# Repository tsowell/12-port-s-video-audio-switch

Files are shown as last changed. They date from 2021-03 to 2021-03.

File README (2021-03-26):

KiCad design, AVR code, and misc CAD files for a 12-port S-Video/audio
switch with VFD display, described in detail here:

https://blog.ldtlb.com/2021/03/25/12-port-s-video-audio-switch.html

The design in the KiCad files has multiple flaws.  Most importantly, the
terminating resistors for the luminance and chroma inputs were omitted, and the
+5VD voltage regualt can become quite hot without a large heatsink.  These are
explained in more detail in the post above.

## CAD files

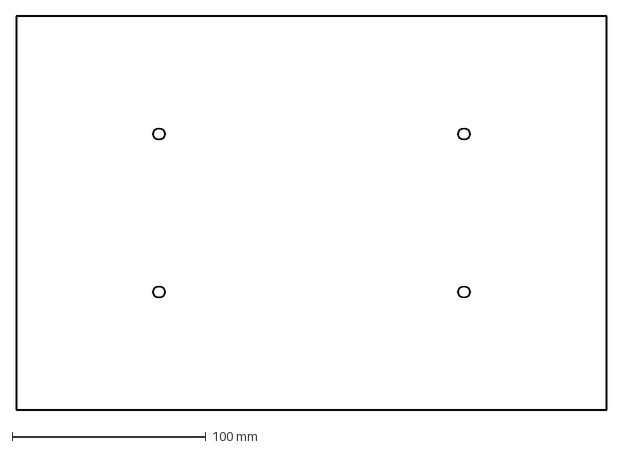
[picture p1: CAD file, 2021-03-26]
dxf/bottom.dxf
304.8 x 203.2 mm

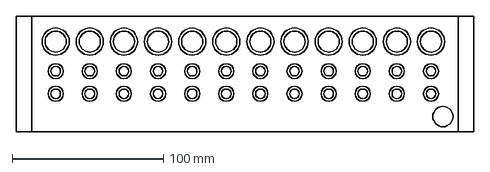
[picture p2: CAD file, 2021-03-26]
dxf/back.dxf
302.2 x 76.2 mm

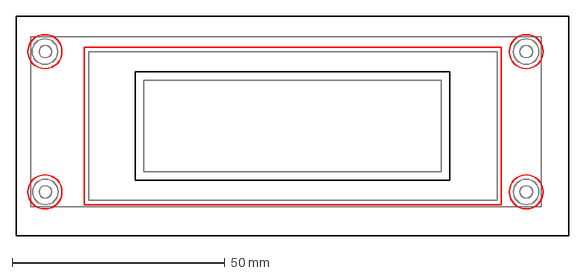
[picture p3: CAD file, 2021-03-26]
dxf/bezel.dxf
129.8 x 51.6 mm

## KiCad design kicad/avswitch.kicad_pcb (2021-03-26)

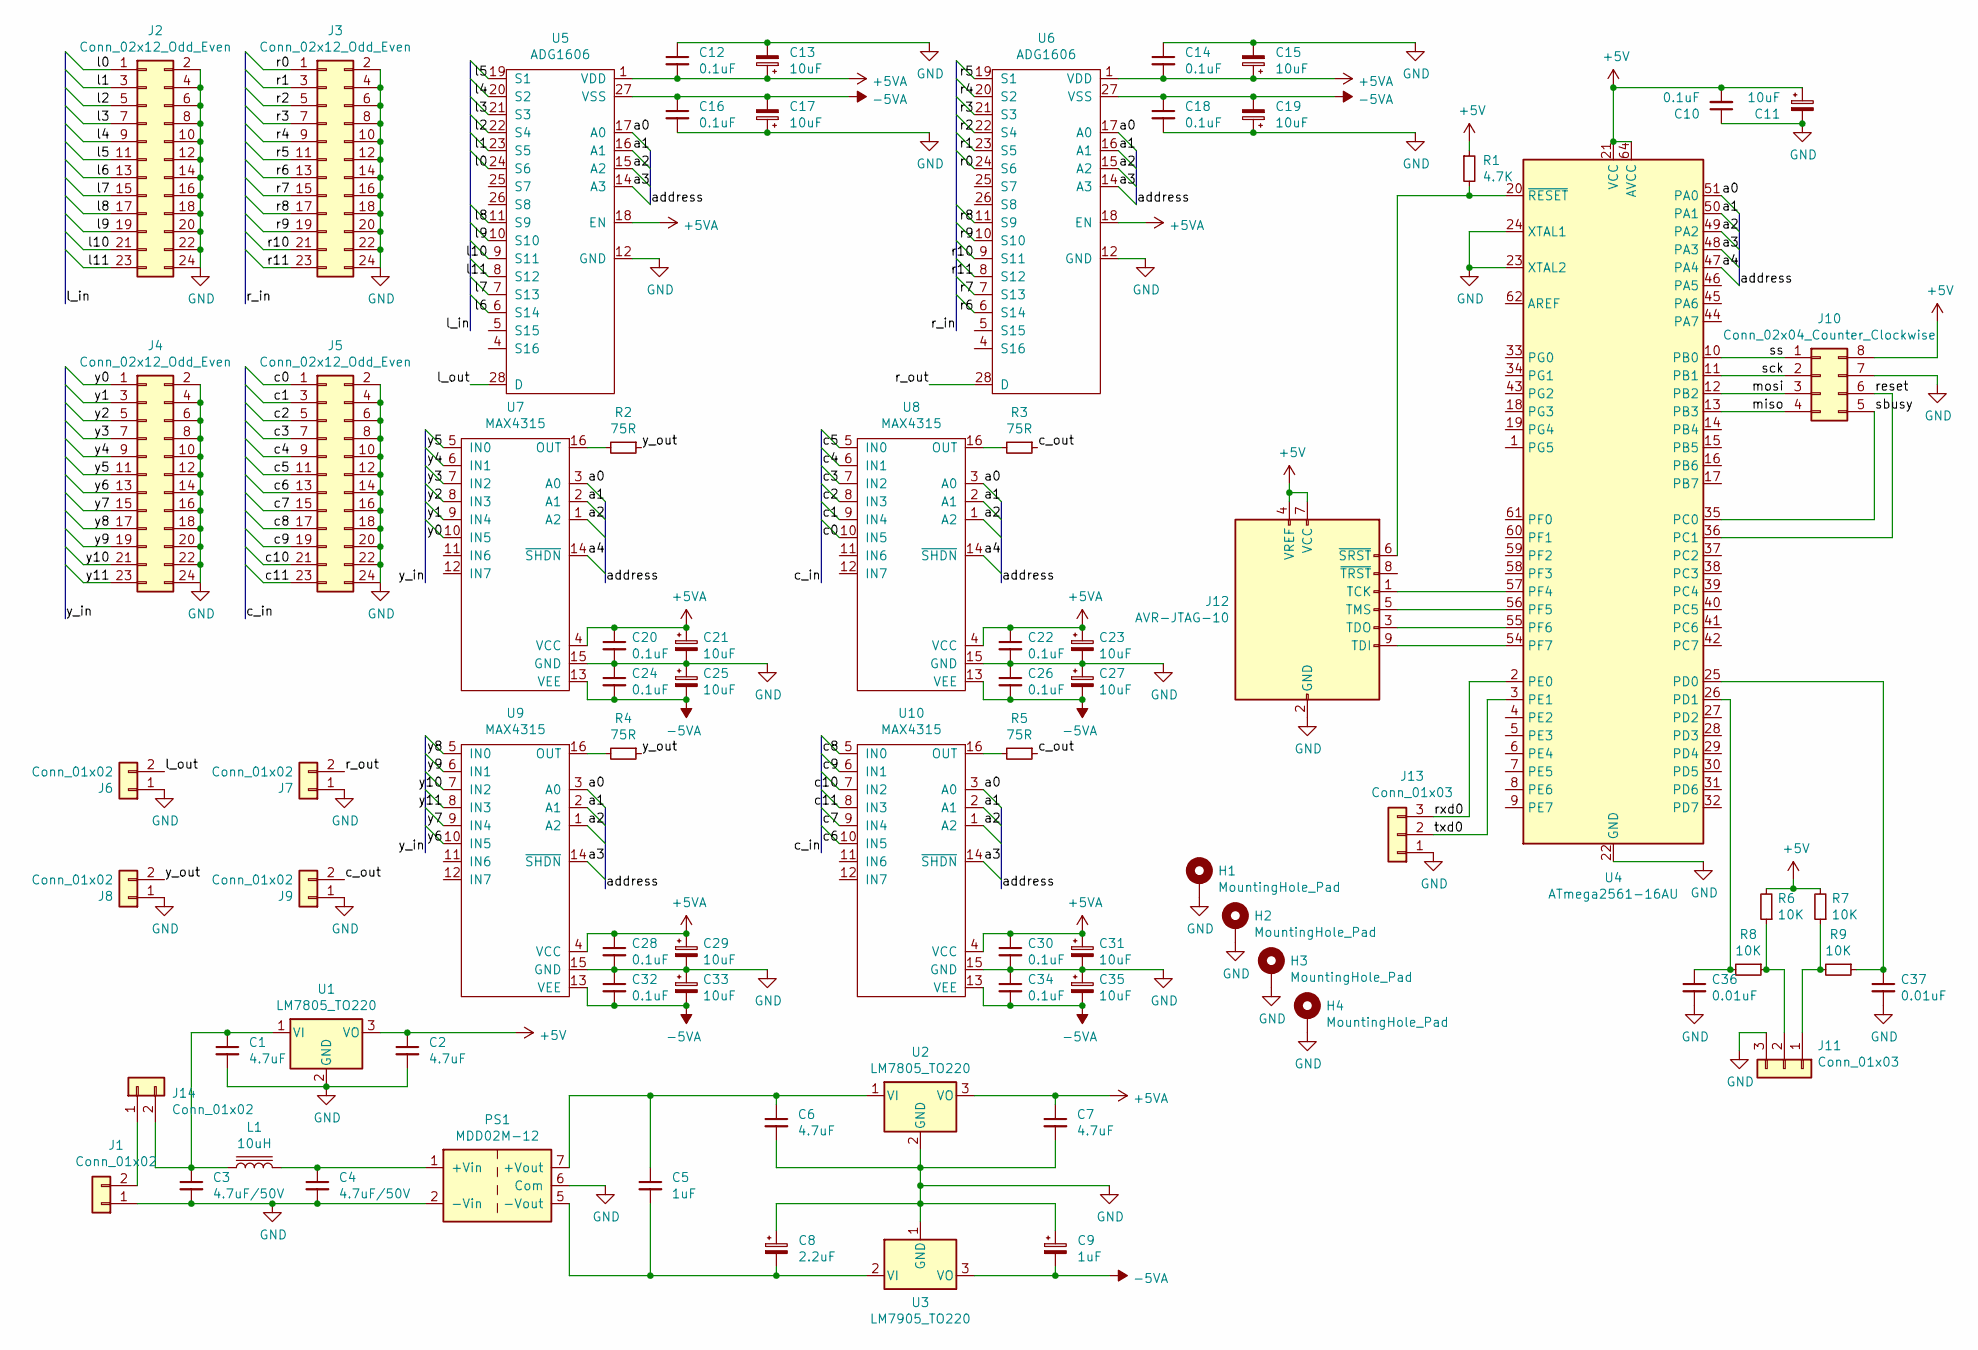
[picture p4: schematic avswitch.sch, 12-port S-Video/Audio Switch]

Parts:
C1, C2, C6, C7: 4.7uF; C_1206_3216Metric_Pad1.42x1.75mm_HandSolder; Part 399-3524-1-ND
C3, C4: 4.7uF/50V; C_1206_3216Metric_Pad1.42x1.75mm_HandSolder; Part 399-11685-1-ND
C5: 1uF; C_1206_3216Metric_Pad1.42x1.75mm_HandSolder; Part 399-1254-1-ND
C8: 2.2uF; CP_EIA-3216-18_Kemet-A_Pad1.58x1.35mm_HandSolder; Part 399-3691-1-ND
C9: 1uF; CP_EIA-3216-18_Kemet-A_Pad1.58x1.35mm_HandSolder; Part 399-3678-1-ND
C10, C12, C14, C16, C18, C20, C22, C24, C26, C28, C30, C32, C34: 0.1uF; C_1206_3216Metric_Pad1.42x1.75mm_HandSolder; Part 399-9305-1-ND
C11, C13, C15, C17, C19, C21, C23, C25, C27, C29, C31, C33, C35: 10uF; CP_Elec_4x5.4; Part 493-2173-1-ND
C36, C37: 0.01uF; C_1206_3216Metric_Pad1.42x1.75mm_HandSolder; Part 399-14645-1-ND
H1, H2, H3, H4: MountingHole_Pad; MountingHole_3.2mm_M3_Pad_Via
J1, J6, J7, J8, J9, J14: Conn_01x02; Molex_KK-254_AE-6410-02A_1x02_P2.54mm_Vertical; Part WM2700-ND
J2, J3, J4, J5: Conn_02x12_Odd_Even; PinHeader_2x12_P2.54mm_Vertical; Part ED10525-ND
J10: Conn_02x04_Counter_Clockwise; PinHeader_2x04_P2.54mm_Vertical; Part 732-5395-ND
J11: Conn_01x03; Molex_KK-254_AE-6410-03A_1x03_P2.54mm_Vertical; Part WM2701-ND
J12: AVR-JTAG-10; PinHeader_2x05_P1.27mm_Vertical; Part 1175-1627-ND
J13: Conn_01x03; PinHeader_1x03_P2.54mm_Vertical
L1: 10uH; L_1206_3216Metric_Pad1.42x1.75mm_HandSolder; Part 541-2607-6-ND
PS1: MDD02M-12; Part 1866-3383-ND
R1: 4.7K; R_1206_3216Metric_Pad1.42x1.75mm_HandSolder; Part 311-4.7KERCT-ND
R2, R3, R4, R5: 75R; R_1206_3216Metric_Pad1.42x1.75mm_HandSolder; Part 311-75ERCT-ND
R6, R7, R8, R9: 10K; R_1206_3216Metric_Pad1.42x1.75mm_HandSolder; Part 311-10KERCT-ND
U1, U2: LM7805_TO220; TO-220-3_Vertical; Part 296-47192-ND
U3: LM7905_TO220; TO-220-3_Vertical; Part LM7905CTNS/NOPB-ND
U4: ATmega2561-16AU; TQFP-64_14x14mm_P0.8mm; Part ATMEGA2561-16AURCT-ND
U5, U6: ADG1606; TSSOP-28_4.4x9.7mm_P0.65mm; Part ADG1606BRUZ-REEL7CT-ND
U7, U8, U9, U10: MAX4315; SOIC-16_3.9x9.9mm_P1.27mm

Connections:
+5V: C2.1, C10.2, C11.1, J10.8, J12.4 (VREF), J12.7 (VCC), R1.1, R6.2, R7.2, U1.3 (VO), U4.21 (VCC), U4.52 (VCC), U4.64 (AVCC)
+5VA: C7.1, C12.2, C13.1, C14.2, C15.1, C20.1, C21.1, C22.1, C23.1, C28.1, C29.1, C30.1, C31.1, U2.3 (VO), U5.1 (VDD), U5.18 (EN), U6.1 (VDD), U6.18 (EN), U7.4 (VCC), U8.4 (VCC), U9.4 (VCC), U10.4 (VCC)
-5VA: C9.2, C16.1, C17.2, C18.1, C19.2, C24.2, C25.2, C26.2, C27.2, C32.2, C33.2, C34.2, C35.2, U3.3 (VO), U5.27 (VSS), U6.27 (VSS), U7.13 (VEE), U8.13 (VEE), U9.13 (VEE), U10.13 (VEE)
/a0: U4.51 (PA0), U5.17 (A0), U6.17 (A0), U7.3 (A0), U8.3 (A0), U9.3 (A0), U10.3 (A0)
/a1: U4.50 (PA1), U5.16 (A1), U6.16 (A1), U7.2 (A1), U8.2 (A1), U9.2 (A1), U10.2 (A1)
/a2: U4.49 (PA2), U5.15 (A2), U6.15 (A2), U7.1 (A2), U8.1 (A2), U9.1 (A2), U10.1 (A2)
/a3: U4.48 (PA3), U5.14 (A3), U6.14 (A3), U9.14 (~SHDN), U10.14 (~SHDN)
/a4: U4.47 (PA4), U7.14 (~SHDN), U8.14 (~SHDN)
/c0: J5.1, U8.10 (IN5)
/c1: J5.3, U8.9 (IN4)
/c2: J5.5, U8.8 (IN3)
/c3: J5.7, U8.7 (IN2)
/c4: J5.9, U8.6 (IN1)
/c5: J5.11, U8.5 (IN0)
/c6: J5.13, U10.10 (IN5)
/c7: J5.15, U10.9 (IN4)
/c8: J5.17, U10.5 (IN0)
/c9: J5.19, U10.6 (IN1)
/c10: J5.21, U10.7 (IN2)
/c11: J5.23, U10.8 (IN3)
/c_out: J9.2, R3.1, R5.1
/l0: J2.1, U5.24 (S6)
/l1: J2.3, U5.23 (S5)
/l2: J2.5, U5.22 (S4)
/l3: J2.7, U5.21 (S3)
/l4: J2.9, U5.20 (S2)
/l5: J2.11, U5.19 (S1)
/l6: J2.13, U5.6 (S14)
/l7: J2.15, U5.7 (S13)
/l8: J2.17, U5.11 (S9)
/l9: J2.19, U5.10 (S10)
/l10: J2.21, U5.9 (S11)
/l11: J2.23, U5.8 (S12)
/l_out: J6.2, U5.28 (D)
/miso: J10.4, U4.13 (PB3)
/mosi: J10.3, U4.12 (PB2)
/r0: J3.1, U6.24 (S6)
/r1: J3.3, U6.23 (S5)
/r2: J3.5, U6.22 (S4)
/r3: J3.7, U6.21 (S3)
/r4: J3.9, U6.20 (S2)
/r5: J3.11, U6.19 (S1)
/r6: J3.13, U6.6 (S14)
/r7: J3.15, U6.7 (S13)
/r8: J3.17, U6.11 (S9)
/r9: J3.19, U6.10 (S10)
/r10: J3.21, U6.9 (S11)
/r11: J3.23, U6.8 (S12)
/r_out: J7.2, U6.28 (D)
/reset: J10.6, U4.36 (PC1)
/rxd0: J13.3, U4.2 (PE0)
/sbusy: J10.5, U4.35 (PC0)
/sck: J10.2, U4.11 (PB1)
/ss: J10.1, U4.10 (PB0)
/txd0: J13.2, U4.3 (PE1)
/y0: J4.1, U7.10 (IN5)
/y1: J4.3, U7.9 (IN4)
/y2: J4.5, U7.8 (IN3)
/y3: J4.7, U7.7 (IN2)
/y4: J4.9, U7.6 (IN1)
/y5: J4.11, U7.5 (IN0)
/y6: J4.13, U9.10 (IN5)
/y7: J4.15, U9.9 (IN4)
/y8: J4.17, U9.5 (IN0)
/y9: J4.19, U9.6 (IN1)
/y10: J4.21, U9.7 (IN2)
/y11: J4.23, U9.8 (IN3)
/y_out: J8.2, R2.1, R4.1
GND: C1.2, C2.2, C3.2, C4.2, C6.2, C7.2, C8.1, C9.1, C10.1, C11.2, C12.1, C13.2, C14.1, C15.2, C16.2, C17.1, C18.2, C19.1, C20.2, C21.2, C22.2, C23.2, C24.1, C25.1, C26.1, C27.1, C28.2, C29.2, C30.2, C31.2, C32.1, C33.1, C34.1, C35.1, C36.2, C37.2, H1.1, H2.1, H3.1, H4.1, J1.1, J2.2, J2.4, J2.6, J2.8, J2.10, J2.12, J2.14, J2.16, J2.18, J2.20, J2.22, J2.24, J3.2, J3.4, J3.6, J3.8, J3.10, J3.12, J3.14, J3.16, J3.18, J3.20, J3.22, J3.24, J4.2, J4.4, J4.6, J4.8, J4.10, J4.12, J4.14, J4.16, J4.18, J4.20, J4.22, J4.24, J5.2, J5.4, J5.6, J5.8, J5.10, J5.12, J5.14, J5.16, J5.18, J5.20, J5.22, J5.24, J6.1, J7.1, J8.1, J9.1, J10.7, J11.3, J12.2 (GND), J12.10 (GND), J13.1, PS1.2 (-Vin), PS1.6 (Com), U1.2 (GND), U2.2 (GND), U3.1 (GND), U4.22 (GND), U4.23 (XTAL2), U4.24 (XTAL1), U4.53 (GND), U4.63 (GND), U5.12 (GND), U6.12 (GND), U7.15 (GND), U8.15 (GND), U9.15 (GND), U10.15 (GND)
unnamed: C1.1, C3.1, J14.2, L1.1, U1.1 (VI)
unnamed: C4.1, L1.2, PS1.1 (+Vin)
unnamed: C5.1, C6.1, PS1.7 (+Vout), U2.1 (VI)
unnamed: C5.2, C8.2, PS1.5 (-Vout), U3.2 (VI)
unnamed: C36.1, R8.2, U4.26 (PD1)
unnamed: C37.1, R9.1, U4.25 (PD0)
unnamed: J1.2, J14.1
unnamed: J11.1, R7.1, R9.2
unnamed: J11.2, R6.1, R8.1
unnamed: J12.1 (TCK), U4.57 (PF4)
unnamed: J12.3 (TDO), U4.55 (PF6)
unnamed: J12.5 (TMS), U4.56 (PF5)
unnamed: J12.6 (~SRST), R1.2, U4.20 (~RESET)
unnamed: J12.9 (TDI), U4.54 (PF7)
unnamed: R2.2, U7.16 (OUT)
unnamed: R3.2, U8.16 (OUT)
unnamed: R4.2, U9.16 (OUT)
unnamed: R5.2, U10.16 (OUT)

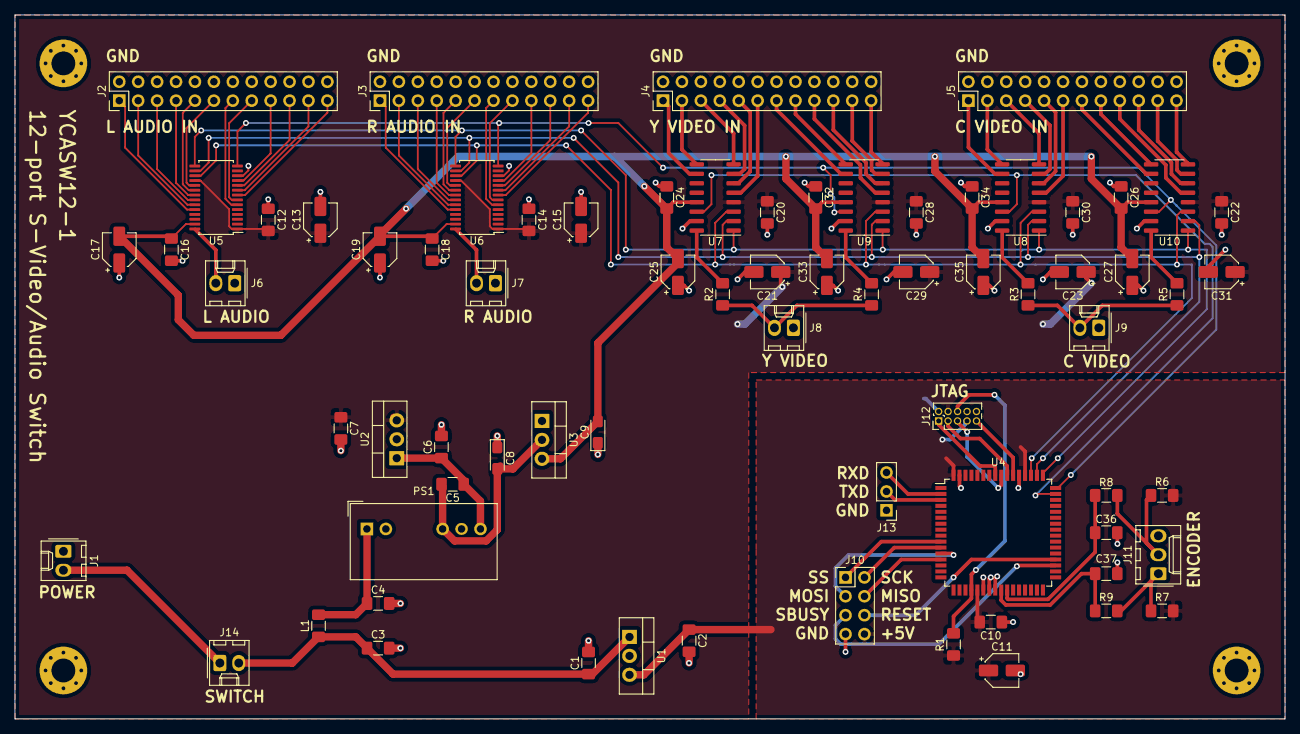
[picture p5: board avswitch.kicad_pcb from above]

Board: 2 copper layers, 170.5 x 94.5 mm, 76 parts (0 on the bottom side), 87 nets.

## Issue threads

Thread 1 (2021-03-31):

Add license information

vazhnov, 2021-03-31:
Hello!

I found link to this project from https://hackaday.com/2021/03/30/custom-built-12-port-a-v-switch-keeps-crt-well-fed/

Could you please add information about license of this repository — is it allowed to copy, change and use the code and board schematic files in any purpose?
It would be great to see any popular open source license.

tsowell, 2021-03-31:
Hi, yes, sorry I forgot that!  I'm releasing the contents of this repository under an MIT license, and I've added the licensing file: (64fa706a436f14960ff93261482801e07a017a8b).  I'm new to hardware licensing, but from what I understand, that should be sufficient.  Please let me know if I did anything wrong though.  Thanks for your interest!

vazhnov, 2021-03-31:
@tsowell , Thank you!

Closed 2021-03-31.

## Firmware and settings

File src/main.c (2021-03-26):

#define F_CPU 8000000UL

#include <string.h>
#include <stdio.h>
#include <stdint.h>
#include <stdlib.h>

#include <avr/io.h>
#include <avr/interrupt.h>
#include <avr/eeprom.h>
#include <util/delay.h>

/* Programmatically-generated header containing bitmap data for ribbon of logos
 * generated from PNG files as well as addresses, display names, and ribbon
 * indexes for each input.  This is where inputs[] is defined!
 */
#include "ribbon.h"

/* Font used for for the uptime scroll.  Also programmatically-generated. */
#include "font.h"


static void
spi_init(void)
{
	/* Set /SS, SCK, and MOSI to output. */
	DDRB |= (1 << PB2) | (1 << PB1) | (1 << PB0);
	/* The AVR SPI system will not drive /SS when it is
	 * set as an output, so set it here in order to select
	 * the device. */
	PORTB &= ~(1 << PB0);

	/* Enable SPI master mode, double speed. */
	SPCR = (1 << SPE) | (1 << MSTR) | (1 << SPI2X);
}

static void
spi_send(unsigned char data)
{
	SPDR = data;
	while (!(SPSR & (1 << SPIF))) {
	}
}


static void
vfd_wait_busy(void)
{
	/* Poll the VFD's busy pin. */
	while (!(PINC & (1 << PC0))) {
	}
}

static void
vfd_wait_notbusy(void)
{
	/* Poll the VFD's busy pin. */
	while ((PINC & (1 << PC0))) {
	}
}

static void
vfd_init(void)
{
	/* Set the VFD reset pin to output. */
	DDRC = (1 << PC1);
	/* Reset VFD with a falling edge on the reset line,
	 * followed by a rising edge 2 ms later.*/
	PORTC = (1 << PC1); /* Reset high. */
	spi_init();
	PORTC = 0x00; /* Reset low. */
	_delay_ms(2);
	PORTC = (1 << PC1); /* Reset high. */

	/* Wait for the VFD to initialize. */
	vfd_wait_busy();
	vfd_wait_notbusy();
	_delay_us(2);
}

static void
vfd_write_byte(unsigned char data)
{
	vfd_wait_notbusy();
	spi_send(data);
}

static void
vfd_write(const unsigned char *data, int len)
{
	while (len--)
		vfd_write_byte(*(data++));
}

static void
vfd_write_bit_image(uint16_t left, uint16_t top,
                    uint16_t width, uint16_t height, const uint8_t *data)
{
	vfd_write_byte(0x1f);
	vfd_write_byte(0x28);
	vfd_write_byte(0x64);
	vfd_write_byte(0x21);
	vfd_write_byte(left & 0x0ff);
	vfd_write_byte(left >> 8);
	vfd_write_byte(top & 0x0ff);
	vfd_write_byte(top >> 8);
	vfd_write_byte(width & 0x0ff);
	vfd_write_byte(width >> 8);
	vfd_write_byte(height & 0x0ff);
	vfd_write_byte(height >> 8);
	vfd_write_byte(1); /* display information (fixed) */
	vfd_write(data, width * height / 8);
}

static void
vfd_brightness(unsigned char n)
{
	vfd_write_byte(0x1f);
	vfd_write_byte(0x58);
	vfd_write_byte(n);
}


/* EEPROM location to store ribbon position. */
#define EEPROM_POS_ADDRESS        (void *)0x000
/* EEPROM location to store uptime data. */
#define EEPROM_BANK0_ADDRESS      (void *)0x100
/* EEPROM location to store write validation. */
#define EEPROM_BANK0_GOOD_ADDRESS (void *)0x002
/* EEPROM location to store duplicate uptime data. */
#define EEPROM_BANK1_ADDRESS      (void *)0x200
/* EEPROM location to store duplicate write validation. */
#define EEPROM_BANK1_GOOD_ADDRESS (void *)0x003

static void
eeprom_write_uptime(const uint32_t *uptimes)
{
	/* Write uptimes to EEPROM.  Store two copies for redundancy.  Each
	 * copy has a flag at EEPROM_BANKN_GOOD_ADDRESS that indicates that the
	 * write was completed.  This is intended to protect against data loss
	 * in the event that the controller is powered down part of the way
	 * through this function. */
	cli();
	eeprom_update_byte(EEPROM_BANK0_GOOD_ADDRESS, 0);
	eeprom_update_block(uptimes, EEPROM_BANK0_ADDRESS,
	                    sizeof(uint32_t) * NUM_INPUTS);
	eeprom_update_byte(EEPROM_BANK0_GOOD_ADDRESS, 1);

	eeprom_update_byte(EEPROM_BANK1_GOOD_ADDRESS, 0);
	eeprom_update_block(uptimes, EEPROM_BANK1_ADDRESS,
	                    sizeof(uint32_t) * NUM_INPUTS);
	eeprom_update_byte(EEPROM_BANK1_GOOD_ADDRESS, 1);
	sei();
}

static void
eeprom_read_uptime(uint32_t *uptimes)
{
	/* Read uptime from EEPROM.  Only read a copy if the flag at
	 * EEPROM_BANKN_GOOD_ADDRESS indicates a complete write. */
	uint8_t bank0_good = 0, bank1_good = 0;

	cli();

	bank0_good = eeprom_read_byte(EEPROM_BANK0_GOOD_ADDRESS);
	bank1_good = eeprom_read_byte(EEPROM_BANK1_GOOD_ADDRESS);

	if (bank0_good) {
		eeprom_read_block(uptimes, EEPROM_BANK0_ADDRESS,
		                  sizeof(uint32_t) * NUM_INPUTS);
	}
	else if (bank1_good) {
		eeprom_read_block(uptimes, EEPROM_BANK1_ADDRESS,
		                  sizeof(uint32_t) * NUM_INPUTS);
	}
	else {
		sei();
		return;
	}

	if (!bank0_good) {
		eeprom_update_byte(EEPROM_BANK0_GOOD_ADDRESS, 0);
		eeprom_update_block(uptimes, EEPROM_BANK0_ADDRESS,
				    sizeof(uint32_t) * NUM_INPUTS);
		eeprom_update_byte(EEPROM_BANK0_GOOD_ADDRESS, 1);
	}
	if (!bank1_good) {
		eeprom_update_byte(EEPROM_BANK1_GOOD_ADDRESS, 0);
		eeprom_update_block(uptimes, EEPROM_BANK1_ADDRESS,
				    sizeof(uint32_t) * NUM_INPUTS);
		eeprom_update_byte(EEPROM_BANK1_GOOD_ADDRESS, 1);
	}
	sei();
}


/* UI state.  Primarily progresses through
 *   S_MENU => S_STOPPED => S_SELECTED => S_CENTERED.
 * with STATE_DELAY delays in between.
 * In the special case that Info is selected in the S_CENTERED state, progress
 * through S_WAITINFOSCROLL => S_INFOSCROLL
 * In any state, rotary encoder movement causes immediate transition to S_MENU.
 * */
volatile static enum {
	S_CENTERED,
	/* The idle state - input is selected, logo is centered.  If Info is
	 * selected, move on to S_WAITINFOSCROLL. */
	S_MENU,
	/* Display visible portion of ribbon, highlight nearest logo, process
	 * rotary encoder movement.  Any movement in any state brings the
	 * device back to S_MENU. */
	S_STOPPED,
	/* Velocity has reached 0 in S_MENU.  Pause before moving on to
	 * S_SELECTED. */
	S_SELECTED,
	/* Center the nearest logo and clear the rest of the ribbon before
	 * moving on to S_CENTERED. */
	S_WAITINFOSCROLL,
	/* Info has been selected.  Pause before scrolling uptimes. */
	S_INFOSCROLL
	/* Scroll uptimes. */
} state = S_STOPPED;

/* Scroll the uptime buffer 1 row every SCROLL_DELAY ticks. */
#define SCROLL_DELAY 4000
/* Ticks to wait before transitioning to the next state in the absense of
 * rotary encoder movement. */
#define STATE_DELAY 32000

/* The last time a state transtition occurred. */
volatile static uint16_t last_ticks = 0;

/* The currently-selected input. */
volatile static int8_t input = 0;


/* Constants and variables for tracking movement on the ribbon.  Motion of the
 * rotary encoder changes velocity, which determines the amount of period
 * change to the position.  Velocity decays over time. */

/* Add velocity to position every POS_INTERVAL ticks. */
#define POS_INTERVAL 500
/* Absolute velocity decreases by 3 every VELOCITY_INTERVAL ticks. */
#define VELOCITY_INTERVAL 4000
#define VELOCITY_DECAY 3

/* pos_ticks counts up to POS_INTERVAL. */
volatile static uint16_t pos_ticks = 0;
/* velocity_ticks counts up to VELOCITY_INTERVAL. */
volatile static uint16_t velocity_ticks = 0;

/* Position on the ribbon.  0 <= pos < ribbon_width
 * 0 is the left-most column. */
volatile static int16_t pos = 0;
/* Velocity of ribbon movement.  -20 < velocity < 20 Positive
 * velocity moves position to the right, negative velocity
 * moves position to the left. */
volatile static int8_t velocity = 0;


enum enc_dir { ENC_DIR_LEFT, ENC_DIR_RIGHT };
volatile static enum enc_dir enc_dir_1 = ENC_DIR_LEFT;
volatile static enum enc_dir enc_dir_0 = ENC_DIR_RIGHT;

/* Shortcuts for setting interrupt trigger conditions in EICRA. */
#define ENC_INT_1_RISE ((1 << ISC11) | (1 << ISC10))
#define ENC_INT_1_FALL ((1 << ISC11)               )
#define ENC_INT_0_RISE ((1 << ISC01) | (1 << ISC00))
#define ENC_INT_0_FALL ((1 << ISC01)               )

static void
encoder_init()
{
	/* Set up encoder ports and interrupts.  This needs to be called every
	 * time the encoder value changes to configure the interrupt triggers
	 * and directions. */

	/* Configure PD0 and PD1 as inputs */
	DDRD &= ~(1 << PD0);
	DDRD &= ~(1 << PD1);

	/* Enable the pull-up resistors */
	PORTD |= (1 << PD0) | (1 << PD1);

	/* PD1:PD0 goes 00 => 01 => 11 => 10 => 00 from left to right, so... */

	/* PP  Configure interrupts based on current encoder value.
	 * DD  enc_dir_1 and enc_dir_0 are passed from the ISRs to
	 * 10  encoder_interrupt().
	 * --
	 * 00: PD1 rise means left, PD0 rise means right
	 * 01: PD0 fall means left, PD1 rise means right
	 * 11: PD1 fall means left, PD0 fall means right
	 * 10: PD0 rise means left, PD1 fall means right
	 * */
	uint8_t d = PIND & 0x03;
        if (d == 0x00) {
		EICRA = ENC_INT_1_RISE | ENC_INT_0_RISE;
		enc_dir_1 = ENC_DIR_LEFT;
		enc_dir_0 = ENC_DIR_RIGHT;
	}
	else if (d == 0x01) {
		EICRA = ENC_INT_1_RISE | ENC_INT_0_FALL;
		enc_dir_1 = ENC_DIR_RIGHT;
		enc_dir_0 = ENC_DIR_LEFT;
	}
	else if (d == 0x03) {
		EICRA = ENC_INT_1_FALL | ENC_INT_0_FALL;
		enc_dir_1 = ENC_DIR_LEFT;
		enc_dir_0 = ENC_DIR_RIGHT;
	}
	else if (d == 0x02) {
		EICRA = ENC_INT_1_FALL | ENC_INT_0_RISE;
		enc_dir_1 = ENC_DIR_RIGHT;
		enc_dir_0 = ENC_DIR_LEFT;
	}

	/* Clear interrupt flags. */
        EIFR |= (1 << INTF1) | (1 << INTF0);
	/* Enable interrupts on both encoder pins. */
	EIMSK |= (1 << INT0) | (1 << INT1);
}

static void
encoder_interrupt(enum enc_dir dir)
{
	/* Called when a rotary encoder interrupt has occurred.  The interrupt
	 * vector supplies the direction set by encoder_init(). */

	/* Transition to the menu state and update pos and velocity. */
	if (dir == ENC_DIR_LEFT) {
		state = S_MENU;

		if (velocity == 0) {
			pos += -1;
			if (pos < 0)
				pos = ribbon_width + pos;
		}
		if (velocity > -20)
			velocity -= VELOCITY_DECAY;
        }
        else {
		state = S_MENU;

		if (velocity == 0) {
			pos += 1;
			pos = pos % ribbon_width;
		}
		if (velocity < 20)
			velocity += VELOCITY_DECAY;
        }
	/* Reinitialize encoder interrupts based on new encoder value. */
	encoder_init();
}

ISR(INT0_vect)
{
        encoder_interrupt(enc_dir_0);
}

ISR(INT1_vect)
{
        encoder_interrupt(enc_dir_1);
}


/* Uptimes for each input.  The first input (info) represents the total uptime.
 * These are incremented by the timer ISR, written to EEPROM periodically, and
 * read back from EEPROM at boot.  */
volatile static uint32_t uptimes[NUM_INPUTS] = { 0 };
/* Set when times are updated by the timer ISR so that the uptime scroll can be
 * redisplayed. */
volatile static uint8_t uptimes_dirty = 1;

/* These are used to dim the display after a certain amount of time is spent
 * on the same input. */
#define DIM_AFTER_MINUTES 2
volatile static uint8_t minutes_this_input = 0;
volatile static uint8_t last_input = 0;

static void
init_uptime_counter()
{
	/* Fire an interrupt every 1 second. */
	TCCR3A = 0;
	TCCR3B |= _BV(WGM32) | _BV(CS32); /* CTC, CLK / 256*/
	TCNT3 = 0;
	/* Timer compare interrupt */
	OCR3A = 31250;
	TIMSK3 |= 1 << OCIE3A;
}

ISR(TIMER3_COMPA_vect)
{
	static uint8_t seconds = 0;
	seconds++;
	if (seconds >= 60) {
		seconds = 0;
		uptimes[0]++;
		if ((state == S_CENTERED) && (inputs[input].address != 0xff)) {
			minutes_this_input++;
			uptimes[input]++;
		}
		uptimes_dirty = 1;
	}
}


static void
render_uptime_line(uint8_t *dst, const char *s)
{
	int c, i;
	for (c = 0; c < 9; c++) {
		if (!s[c])
			break;
		/* Characters are 5 pixels wide.  Only use /[0-9][A-Z]dhm/
		 * font[] is ordered:
		 * ABCDEFGHIJKLMNOPQRSTUVWXYZ0123456789dhms */
		for (i = 0; i < 5; i++) {
			if ((s[c] >= '0') && (s[c] <= '9'))
				dst[c*5+i] = font[s[c]-'0'][i];
			else if ((s[c] >= 'A') && (s[c] <= 'Z'))
				dst[c*5+i] = font[s[c]-'A'+10][i];
			else if (s[c] == 'd')
				dst[c*5+i] = font[36][i];
			else if (s[c] == 'h')
				dst[c*5+i] = font[37][i];
			else if (s[c] == 'm')
				dst[c*5+i] = font[38][i];
		}
	}
}

static void
render_uptime(uint8_t *dst, const uint32_t *uptimes)
{
	char s[9];
	uint32_t time;
	int t;
	for (t = 0; t < NUM_INPUTS; t++) {
		render_uptime_line(&dst[80+t*2*40], inputs[t].abbrev);
		time = uptimes[inputs[t].id];
		if ((time / 60) >= 100) {
			sprintf(s, "%2id%2ih",
			        (short)((time / 60) / 24),
				(short)((time % (24 * 60)) / 60));
		}
		else {
			sprintf(s, "%2ih%2im",
			        (short)(time / 60),
				(short)(time % 60));
		}
		render_uptime_line(&dst[80+t*2*40+40], s);
	}
}


static void
blit_ribbon(uint8_t *buf, uint16_t edge0, uint16_t edge1, uint8_t blank)
{
	/* Render the ribbon.  If blank evaluates to true, only render the part
	 * of the ribbon between edge0 and edge1. */
	int16_t px, rx;
	uint8_t *dst, *src;

	/* One column at a time. */
	for (px = 0; px < 140; px++) {
		/* rx is the column for ribbon_pixel to render.  Wrap the
		 * column if <0 or >ribbon_width */
		rx = pos - 70 + px;
		if (rx < 0)
			rx += ribbon_width;
		else
			rx %= ribbon_width;
		dst = &buf[px * 4];
		src = &ribbon_pixel[rx * 4];
		if ((input >= 0) && (rx >= edge0) && (rx < edge1)) {
			/* Render selected logo between edge0 and edge1.  This
			 * is drawn with light pixels on a dark background.
			 * The 0x80 and 0x01 masks below round off the corners
			 * of the black background. */
			if (!blank && (rx == edge0))
				*dst++ = 0x80 | *src++;
			else if (!blank && (rx == (edge1 - 1)))
				*dst++ = 0x80 | *src++;
			else
				*dst++ = *src++;
			*dst++ = *src++;
			*dst++ = *src++;
			if (!blank && (rx == edge0))
				*dst++ = 0x01 | *src++;
			else if (!blank && (rx == (edge1 - 1)))
				*dst++ = 0x01 | *src++;
			else
				*dst++ = *src++;
		}
		else {
			if (blank
			    && ((rx < edge0) || (rx >= edge1))) {
				/* If blank is enabled, don't render outside of
				 * edge0 and edge1. */
				*dst++ = 0;
				*dst++ = 0;
				*dst++ = 0;
				*dst++ = 0;
			}
			else {
				/* Render the area outside of edge0 and edge1
				 * inverted - dark pixels on a light
				 * background. */
				*dst++ = ~(*src++);
				*dst++ = ~(*src++);
				*dst++ = ~(*src++);
				*dst++ = ~(*src++);
			}
		}
	}


}

static void
blit_uptime(uint8_t *buf, const uint8_t *utbuf,
            uint16_t edge0, uint16_t edge1,
	    uint8_t tline, uint8_t trow)
{
	/* Blit 4 lines of text worth of pixels from the uptime buffer into a
	 * window in the main buffer.  tline is the line of text to draw first.
	 * trow is the row within that line to draw first.*/

	/* This is a bit of a mess and should probably just be rewritten if it
	 * ever needs to be changed. */

	uint8_t r;
	int16_t px, rx;
	uint8_t *dst;
	const uint8_t *src;

	/* r is the line of text offset to render. */
	for (r = 0; r < 4; r++) {
		/* px is the column offset in both buf and utbuf. */
		for (px = 0; px < 40; px++) {
			/* rx is the first column of buf to blit into. */
			rx = edge0 - pos + 70 + 2;
			dst = &buf[(rx + px) * 4 + r];
			/* The + 2 is for the two lines of padding in the
			 * uptime buffer. */
			src = &utbuf[((tline + r) %
			             (2 * (NUM_INPUTS) + 2)) * 40 + px];

			if (trow == 0) {
				/* If we started with the 0th column we can do
				 * a straight copy. */
				*dst = *src;
			}
			else {
				/* Otherwise we need to shift the pixels up and
				 * merge them with part of the next line. */
				if (r < 4) {
					if ((tline + r) == (2 * NUM_INPUTS) + 2 - 1) {
						/* The last line in the uptime
						 * buffer needs to be shifted
						 * and combined with the first
						 * line in the uptime buffer in
						 * order to wrap properly. */
						*dst = (utbuf[px] >> (8 - trow)) | (*src << trow);
					}
					else {
						/* Other lines just need to be
						 * shifted and merged with the
						 * first part of the next line.
						 * */
						*dst = (*(src+40) >> (8 - trow)) | (*src << trow);
					}
				}
				else {
					/* And the final line is just the first
					 * part of the next line. */
					*dst = *src << trow;
				}
			}
			/* Finally, clear the first and last row of pixels of
			 * the window to form top and bottom margins. */
			if (r == 0) {
				*dst &= 0x7f;
			}
			else if (r == 3) {
				*dst &= 0xfe;
			}
		}
	}

}

/* An unused multiplexer address. */
#define UNUSED_INPUT 0x17

static int8_t
nearest_input(int16_t pos)
{
	uint8_t i;
	pos = pos % ribbon_width;
	for (i = 0; i < 12; i++) {
		if (inputs[i].address) {
			if ((pos >= (inputs[i].begin))
			    && (pos <= (inputs[i].end))) {
				return i;
			}
		}
	}
	return -1;
}

int
main(void)
{
	uint16_t my_ticks;
	uint8_t blank;
	/* Main video buffer.  Both this and the uptime buffer are in the same
	 * format used by the VFD interface - column-major order, each byte is
	 * 8 consecutive vertical pixels. */
	uint8_t buf[140 * 4] = { 0 };
	/* Uptime buffer, blitted into the video buffer with vertical scrolling
	 * when Info input is selected.  The buffer is 40 pixels wide, and each
	 * line of text takes 40 bytes.  The buffer starts with two empty lines
	 * for spacing, followed by two lines for each input. */
	uint8_t utbuf[80 + 2 * 40 * (NUM_INPUTS)] = { 0 };

	/* edge0 and edge1 are the left and right column boundaries of the
	 * current logo in the ribbon. */
	int16_t edge0 = inputs[0].begin, edge1 = inputs[0].end;


	/* Set multiplexer address pins to outputs. */
	DDRA = 0x1f;
	/* Select an unsed input. */
	PORTA = UNUSED_INPUT;

	vfd_init();
	vfd_brightness(0x08);

	encoder_init();

	sei();

	/* Load previous state */
	pos = eeprom_read_word(EEPROM_POS_ADDRESS);
	if ((pos < 0) || (pos >= ribbon_width)) {
		pos = 0;
	}
	eeprom_read_uptime((uint32_t *)uptimes);

	/* Set up general purpose counter for timing pos, velocity updates and
	 * state transition delays. */
	TCCR1A = 0;
	TCCR1B = _BV(CS12); /* CLK / 256*/
	TCNT1 = 0;

	init_uptime_counter();

	/* Enable writes to clock prescalar. */
	CLKPR = _BV(CLKPCE);
	/* Set clock prescalar division factor to 1. */
	CLKPR = 0;

	while (1) {
		/* The main loop starts with an empty video buffer. */
		memset(buf, 0, 140 * 4);

		/* If any of the uptimes have changed, redraw the whole
		 * vertical uptime buffer. */
		if (uptimes_dirty) {
			uptimes_dirty = 0;
			render_uptime(utbuf, (uint32_t *)uptimes);
			eeprom_write_uptime((uint32_t *)uptimes);
		}

		my_ticks = TCNT1;

		if (state == S_MENU) {
			vfd_brightness(0x08);
			/* Apply velocity to position and decay to velocity. */
			if ((my_ticks - pos_ticks) >= POS_INTERVAL) {
				pos += velocity;
				if (pos < 0)
					pos += ribbon_width;
				else
					pos %= ribbon_width;
				pos_ticks = my_ticks;
			}
			if ((my_ticks - velocity_ticks) >= VELOCITY_INTERVAL) {
				if (velocity < 0)
					velocity++;
				else if (velocity > 0)
					velocity--;
				velocity_ticks = my_ticks;
			}
		}

		/* Find the nearest input to the current position on the
		 * ribbon.  This is used in a few states below, and edge0 and
		 * edge1 are important for rendering the UI. */
		input = nearest_input(pos);
		if (input >= 0) {
			edge0 = inputs[input].begin;
			edge1 = inputs[input].end;
		}

		if ((velocity == 0) && (state == S_MENU)) {
			/* Due to lack of rotary encoder movement, velocity has
			 * decayed to 0. */
			state = S_STOPPED;
			last_ticks = my_ticks;
		}
		else if ((state == S_STOPPED) &&
		    ((my_ticks - last_ticks) >= STATE_DELAY)) {
			/* After a delay there is still no movement, so we have
			 * a selection. */
			state = S_SELECTED;
			last_ticks = my_ticks;
		}
		else if ((state == S_SELECTED)) {
			if ((pos <= (inputs[input].center + 1))
			    && (pos >= (inputs[input].center - 1))) {
				/* Move on to S_CENTERED if the nearest input
				 * is centered in the display. */
				pos = inputs[input].center;
				state = S_CENTERED;
				eeprom_update_word(EEPROM_POS_ADDRESS, pos);
				last_ticks = my_ticks;
			}
			else if ((my_ticks - last_ticks) >= 40) {
				/* Otherwise, automatically scroll left or
				 * right until the nearest input is centered in
				 * the display. */
				uint8_t diff = abs(pos - inputs[input].center);
				if ((pos < 100) && (inputs[input].center >= (ribbon_width - 100))) {
					pos -= diff / 3 + 1;
				}
				else if (pos < inputs[input].center) {
					pos += diff / 3 + 1;
				}
				else {
					pos -= diff / 3 + 1;
				}
				last_ticks = my_ticks;
			}
		}
		else if ((inputs[input].address == 0xff)
		    && ((state == S_CENTERED))) {
			/* If the info logo is centered, pause before
			 * displaying the uptimes. */
			state = S_WAITINFOSCROLL;
			last_ticks = my_ticks;
		}
		else if ((state == S_WAITINFOSCROLL)
		    && ((my_ticks - last_ticks) >= STATE_DELAY)) {
			/* Time to display the uptimes. */
			state = S_INFOSCROLL;
			last_ticks = my_ticks;
		}
		else if (state == S_CENTERED) {
			/* If another logo is cented, latch the corresponding
			 * address onto the multiplexer address bus. */
			if ((input >= 1) && (input < NUM_INPUTS))
				PORTA = inputs[input].address;
			else
				PORTA = UNUSED_INPUT;

			/* Dim the display after after the same logo has been
			 * centered for a while. */
			if (last_input != input) {
				minutes_this_input = 0;
				last_input = input;
			}

			if (minutes_this_input >= DIM_AFTER_MINUTES)
				vfd_brightness(0x01);
		}


		/* In these states, only render the selected logo part of the
		 * ribbon. */
		blank = ((state == S_SELECTED)
		         || (state == S_WAITINFOSCROLL)
		         || (state == S_INFOSCROLL)
		         || (state == S_CENTERED));
		/* Blit the visible portion of the ribbon to the video buffer.
		 * */
		blit_ribbon(buf, edge0, edge1, blank);

		if (state == S_INFOSCROLL) {
			/* Scroll and blit the uptime buffer into a window of
			 * the video buffer. */
			uint8_t tline = 0;
			uint8_t trow = 0;
			if ((my_ticks - last_ticks) >= SCROLL_DELAY) {
				last_ticks = my_ticks;
				trow++;
				if (trow >= 8) {
					tline++;
					trow = 0;
				}
				if (tline >= (2 * (NUM_INPUTS) + 2))
					tline = 0;
			}
			blit_uptime(buf, utbuf, edge0, edge1, tline, trow);
		}

		/* Write out the video buffer to the VFD! */
		vfd_write_bit_image(0, 0, 140, 32, buf);
	}
	return 0;
}
